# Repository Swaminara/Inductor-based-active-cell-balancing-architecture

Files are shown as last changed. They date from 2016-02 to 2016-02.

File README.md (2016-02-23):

# Inductor-based-active-cell-balancing-architecture
This repository contains the hardware design files of a modular inductor-based active cell balancing architecture proposed in CODES+ISSS '14 under the title "Verification of Balancing Architectures for Modular Batteries".

If you want to use the hardware files in this repository in your scientific publications, please reference it by the following bibtex citation

@inproceedings{lsn:2014,
  url = {  https://lukasiewycz.github.io/pdf/2014-CODES%2BISSS-Verification%20of%20Balancing%20Architectures%20for%20Modular%20Batteries.pdf  },
  doi = { 10.1145/2656075.2656104 },
  pages = { 30:1--30:10 },
  month = { 10 },
  year = { 2014 },
  location = { India },
  booktitle = { Proceedings of the 12th International Conference on Hardware/Software Codesign and System Synthesis (CODES+ISSS 2014) },
  author = { Martin Lukasiewycz and Sebastian Steinhorst and Swaminathan Narayanaswamy },
  title = { Verification of Balancing Architectures for Modular Batteries },
}

This repository is protected under the MIT license as attached.

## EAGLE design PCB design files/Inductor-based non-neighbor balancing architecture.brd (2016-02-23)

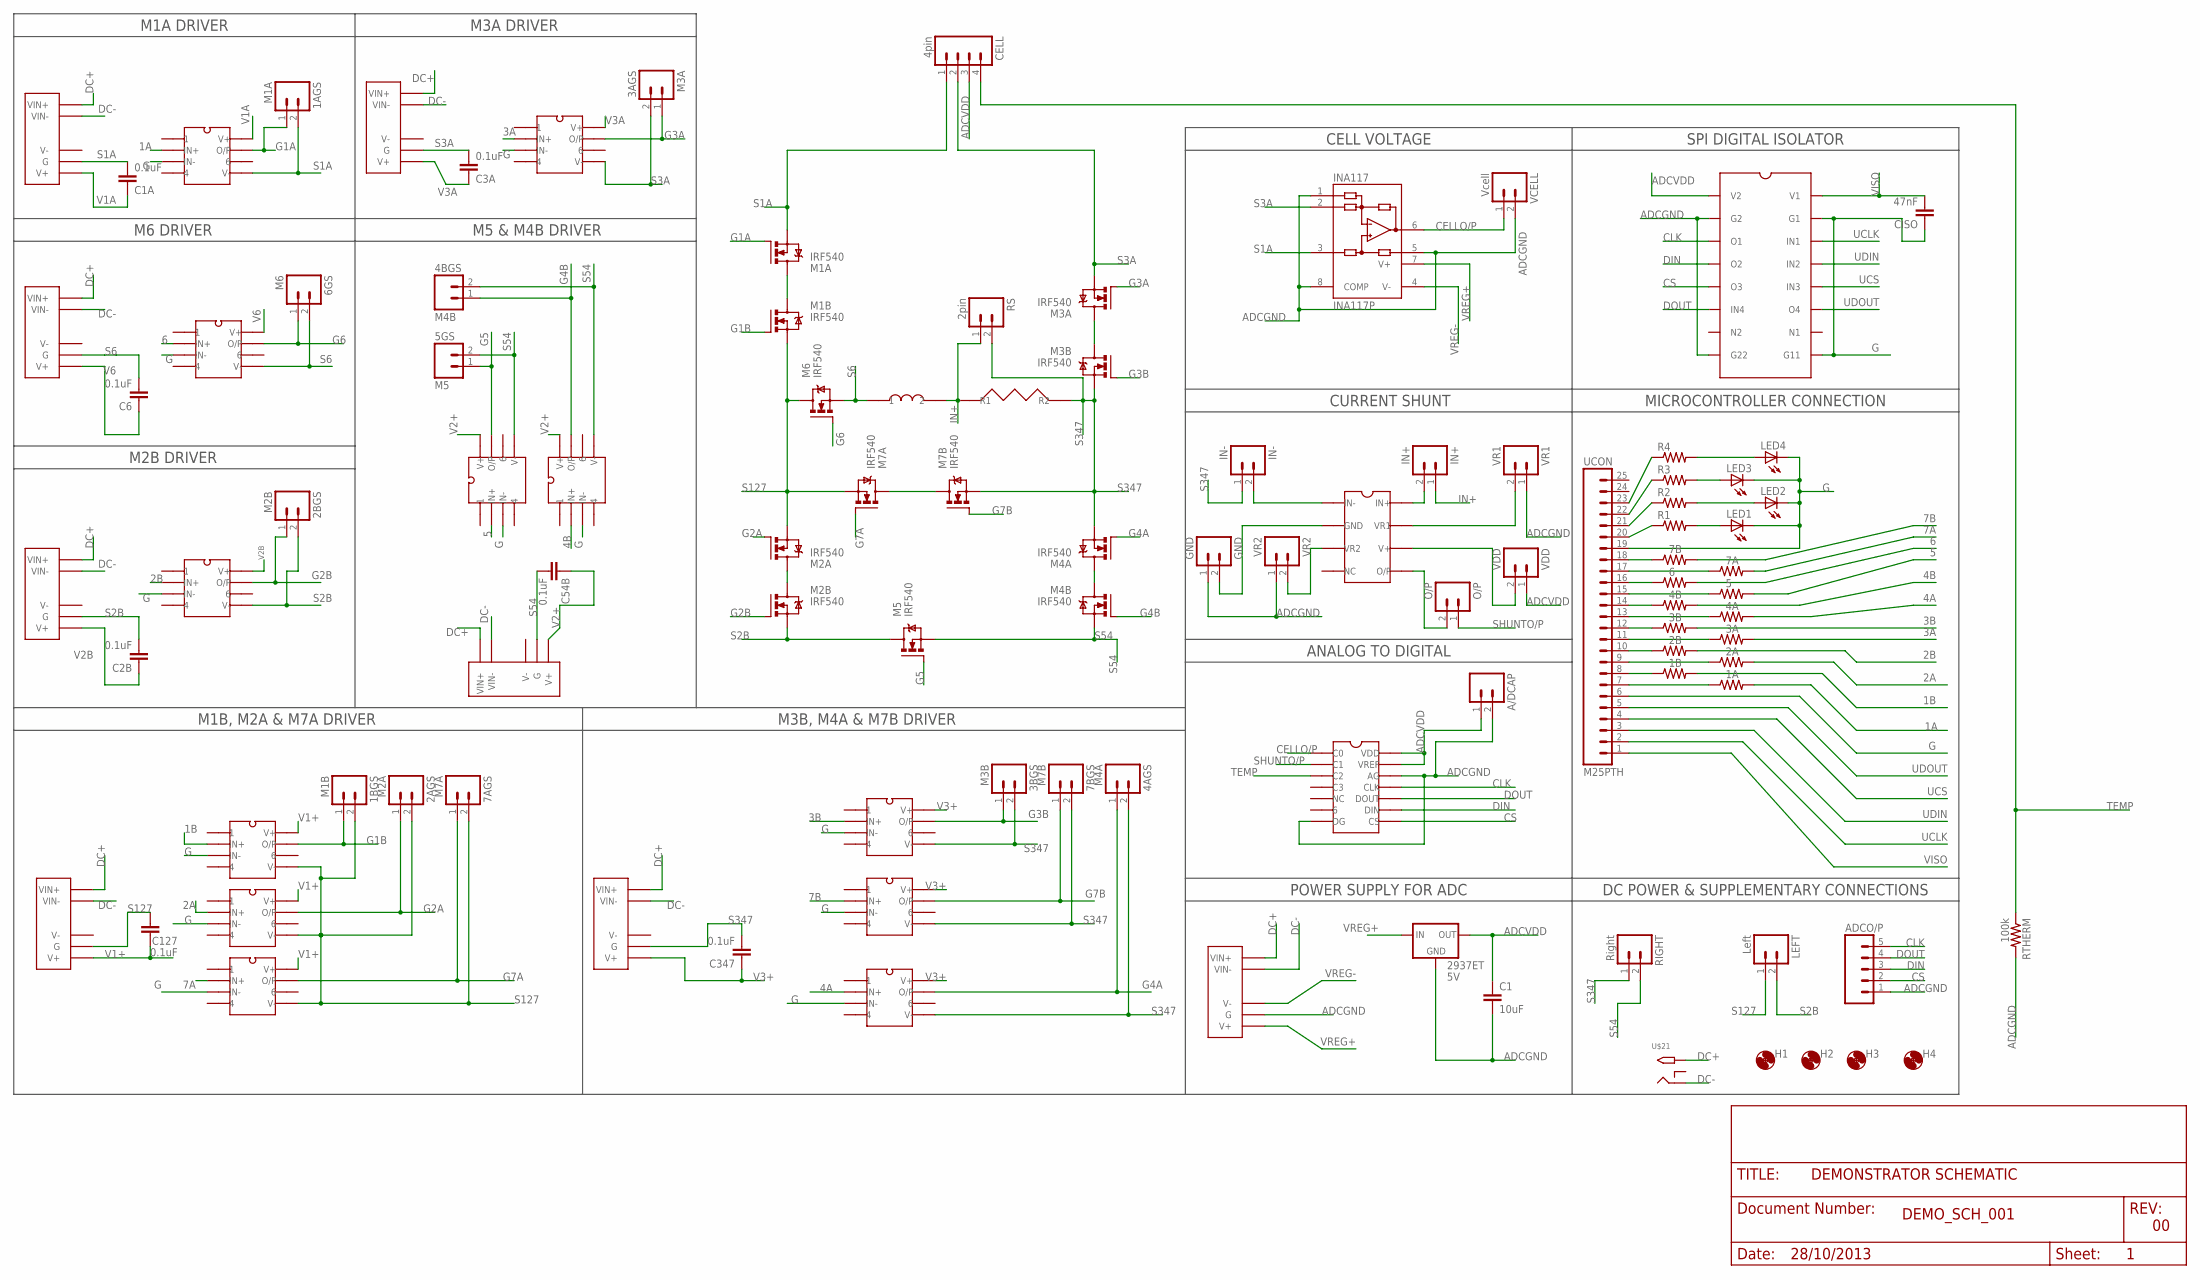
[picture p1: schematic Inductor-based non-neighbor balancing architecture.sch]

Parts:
1A, 1B, 2A, 2B, 3A, 3B, 4A, 4B, 5, 6, 7A, 7B: 220; AXIAL-0.5
1AGS: M1A; 1X02
1BGS: M1B; 1X02
2AGS: M2A; 1X02
2BGS: M2B; 1X02
3AGS: M3A; 1X02
3BGS: M3B; 1X02
4AGS: M4A; 1X02
4BGS: M4B; 1X02
5GS: M5; 1X02
6GS: M6; 1X02
7AGS: M7A; 1X02
7BGS: M7B; 1X02
2937ET: 5V; 78XXS
A/DCAP: M02PTH; 1X02
AD8210: CSM
ADC: ADC; DIL14
ADCO/P: M05PTH; 1X05
C1: 10uF; CAP-PTH-5MM
C1A, C2B, C3A, C6, C54B, C127, C347: 0.1uF; CAP-PTH-5MM
CELL: 4pin; 1X04
CISO: 47nF; CAP-PTH-5MM
DC/DC1A: 1A; DC-DC
DC/DC2B: 2B; DC-DC
DC/DC3A: 3A; DC-DC
DC/DC6: 6; DC-DC
DC/DC45: 4B5; DC-DC
DC/DC127: 1B2A7A; DC-DC
DC/DC347: 3B4A7B; DC-DC
DC/DC-ADC: ADC; DC-DC
GND: GND; 1X02
H1, H2, H3, H4: MOUNT-HOLE3.0; 3,0
HCPL902J: HCPL902
IN+: IN+; 1X02
IN-: IN-; 1X02
INA117: INA117P; DIL08
LED1, LED2, LED3, LED4: LEDCHIPLED_0805; CHIPLED_0805
LEFT: Left; 1X02
M1A, M1B, M2A, M2B, M3A, M3B, M4A, M4B, M5, M6, M7A, M7B: IRF540; TO220BV
M1AD: M1A; OPTO3180
M1BD: M1B; OPTO3180
M2AD: M2A; OPTO3180
M2BD: M2B; OPTO3180
M3AD: M3A; OPTO3180
M3BD: M3B; OPTO3180
M4AD: M4A; OPTO3180
M4BD: M4B; OPTO3180
M5D: M5; OPTO3180
M6D: M6; OPTO3180
M7AD: M7A; OPTO3180
M7BD: M7B; OPTO3180
O/P: O/P; 1X02
R1, R2, R3, R4: R-US_R0805; R0805
RIGHT: Right; 1X02
RS: 2pin; 1X02
RTHERM: 100k; AXIAL-0.5
U$1: INDFINAL; IND1MHFINAL
U$3: RSHUNT
U$21: 2.1MMJACKTHM; PJ-102A
UCON: M25PTH; 1X25
VCELL: Vcell; 1X02
VDD: VDD; 1X02
VR1: VR1; 1X02
VR2: VR2; 1X02

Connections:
1A: 1A.P$2 (2), M1AD.IN+
1B: 1B.P$2 (2), M1BD.IN+
2A: 2A.P$2 (2), M2AD.IN+
2B: 2B.P$2 (2), M2BD.IN+
3A: 3A.P$2 (2), M3AD.IN+
3B: 3B.P$2 (2), M3BD.IN+
4A: 4A.P$2 (2), M4AD.IN+
4B: 4B.P$2 (2), M4BD.IN+
5: 5.P$2 (2), M5D.IN+
6: 6.P$2 (2), M6D.IN+
7A: 7A.P$2 (2), M7AD.IN+
7B: 7B.P$2 (2), M7BD.IN+
ADCGND: 2937ET.GND, A/DCAP.2, ADC.AGND (AG), ADC.DGND (DG), ADCO/P.1, C1.2, DC/DC-ADC.G, GND.1, HCPL902J.G2, HCPL902J.G22, INA117.1 (REFB), INA117.5 (REFA), INA117.8 (COMP), RTHERM.P$2 (2), VCELL.2, VR1.1, VR2.1
ADCVDD: 2937ET.OUT, A/DCAP.1, ADC.VDD, ADC.VREF, C1.1, CELL.3, HCPL902J.V2, VDD.1
CELLO/P: ADC.CH0 (C0), INA117.6 (OUT), VCELL.1
CLK: ADC.CLK, ADCO/P.5, HCPL902J.OUT1 (O1)
CS: ADC.CS, ADCO/P.2, HCPL902J.OUT3 (O3)
DC+: DC/DC1A.VIN+, DC/DC2B.VIN+, DC/DC3A.VIN+, DC/DC6.VIN+, DC/DC45.VIN+, DC/DC127.VIN+, DC/DC347.VIN+, DC/DC-ADC.VIN+, U$21.TIP
DC-: DC/DC1A.VIN-, DC/DC2B.VIN-, DC/DC3A.VIN-, DC/DC6.VIN-, DC/DC45.VIN-, DC/DC127.VIN-, DC/DC347.VIN-, DC/DC-ADC.VIN-, U$21.RING
DIN: ADC.DIN, ADCO/P.3, HCPL902J.OUT2 (O2)
DOUT: ADC.DOUT, ADCO/P.4, HCPL902J.IN4
G: CISO.1, HCPL902J.G1, HCPL902J.G11, LED1.C, LED2.C, LED3.C, LED4.C, M1AD.IN-, M1BD.IN-, M2AD.IN-, M2BD.IN-, M3AD.IN-, M3BD.IN-, M4AD.IN-, M4BD.IN-, M5D.IN-, M6D.IN-, M7AD.IN-, M7BD.IN-, UCON.6, UCON.19
G1A: 1AGS.1, M1A.G, M1AD.O/P
G1B: 1BGS.1, M1B.G, M1BD.O/P
G2A: 2AGS.1, M2A.G, M2AD.O/P
G2B: 2BGS.1, M2B.G, M2BD.O/P
G3A: 3AGS.1, M3A.G, M3AD.O/P
G3B: 3BGS.1, M3B.G, M3BD.O/P
G4A: 4AGS.1, M4A.G, M4AD.O/P
G4B: 4BGS.1, M4B.G, M4BD.O/P
G5: 5GS.1, M5.G, M5D.O/P
G6: 6GS.1, M6.G, M6D.O/P
G7A: 7AGS.1, M7A.G, M7AD.O/P
G7B: 7BGS.1, M7B.G, M7BD.O/P
IN+: IN+.1, RS.1, U$1.2, U$3.R1
unnamed: M1A.D, M1B.D
unnamed: M4A.D, M4B.D
unnamed: AD8210.VR2, VR2.2
unnamed: M7A.D, M7B.D
unnamed: M2A.D, M2B.D
unnamed: AD8210.IN-, IN-.2
unnamed: AD8210.GND, GND.2
unnamed: AD8210.V+, VDD.2
unnamed: M3A.D, M3B.D
unnamed: AD8210.O/P, O/P.2
unnamed: AD8210.VR1, VR1.2
unnamed: AD8210.IN+, IN+.2
unnamed: 1A.P$1 (1), UCON.7
unnamed: 1B.P$1 (1), UCON.8
unnamed: 2A.P$1 (1), UCON.9
unnamed: 2B.P$1 (1), UCON.10
unnamed: 3A.P$1 (1), UCON.11
unnamed: 3B.P$1 (1), UCON.12
unnamed: 4A.P$1 (1), UCON.13
unnamed: 4B.P$1 (1), UCON.14
unnamed: 5.P$1 (1), UCON.15
unnamed: 6.P$1 (1), UCON.16
unnamed: 7A.P$1 (1), UCON.17
unnamed: 7B.P$1 (1), UCON.18
unnamed: LED2.A, R2.2
unnamed: LED1.A, R1.2
unnamed: LED4.A, R4.2
unnamed: R2.1, UCON.21
unnamed: R3.1, UCON.22
unnamed: LED3.A, R3.2
unnamed: R4.1, UCON.23
R4: R1.1, UCON.20
S1A: 1AGS.2, C1A.2, CELL.1, DC/DC1A.G, INA117.3 (+IN), M1A.S, M1AD.V-
S2B: 2BGS.2, C2B.2, DC/DC2B.G, LEFT.2, M2B.S, M2BD.V-, M5.D
S3A: 3AGS.2, C3A.2, CELL.2, DC/DC3A.G, INA117.2 (-IN), M3A.S, M3AD.V-
S6: 6GS.2, C6.2, DC/DC6.G, M6.S, M6D.V-, U$1.1
S54: 4BGS.2, 5GS.2, C54B.2, DC/DC45.G, M4B.S, M4BD.V-, M5.S, M5D.V-, RIGHT.2
S127: 1BGS.2, 2AGS.2, 7AGS.2, C127.2, DC/DC127.G, LEFT.1, M1B.S, M1BD.V-, M2A.S, M2AD.V-, M6.D, M7A.S, M7AD.V-
S347: 3BGS.2, 4AGS.2, 7BGS.2, C347.2, DC/DC347.G, IN-.1, M3B.S, M3BD.V-, M4A.S, M4AD.V-, M7B.S, M7BD.V-, RIGHT.1, RS.2, U$3.R2
SHUNTO/P: ADC.CH1 (C1), O/P.1
TEMP: ADC.CH2 (C2), CELL.4, RTHERM.P$1 (1)
UCLK: HCPL902J.IN1, UCON.2
UCS: HCPL902J.IN3, UCON.4
UDIN: HCPL902J.IN2, UCON.3
UDOUT: HCPL902J.OUT4 (O4), UCON.5
V1+: C127.1, DC/DC127.V+, M1BD.V+, M2AD.V+, M7AD.V+
V1A: C1A.1, DC/DC1A.V+, M1AD.V+
V2+: C54B.1, DC/DC45.V+, M4BD.V+, M5D.V+
V2B: C2B.1, DC/DC2B.V+, M2BD.V+
V3+: C347.1, DC/DC347.V+, M3BD.V+, M4AD.V+, M7BD.V+
V3A: C3A.1, DC/DC3A.V+, M3AD.V+
V6: C6.1, DC/DC6.V+, M6D.V+
VISO: CISO.2, HCPL902J.V1, UCON.1
VREG+: 2937ET.IN, DC/DC-ADC.V+, INA117.7 (V+)
VREG-: DC/DC-ADC.V-, INA117.4 (V-)

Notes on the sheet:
M1A DRIVER
M3A DRIVER
M6 DRIVER
M5 & M4B DRIVER
M2B DRIVER
M1B, M2A & M7A DRIVER
M3B, M4A & M7B DRIVER
CELL VOLTAGE
CURRENT SHUNT
ANALOG TO DIGITAL
SPI DIGITAL ISOLATOR
MICROCONTROLLER CONNECTION
POWER SUPPLY FOR ADC
DC POWER & SUPPLEMENTARY CONNECTIONS

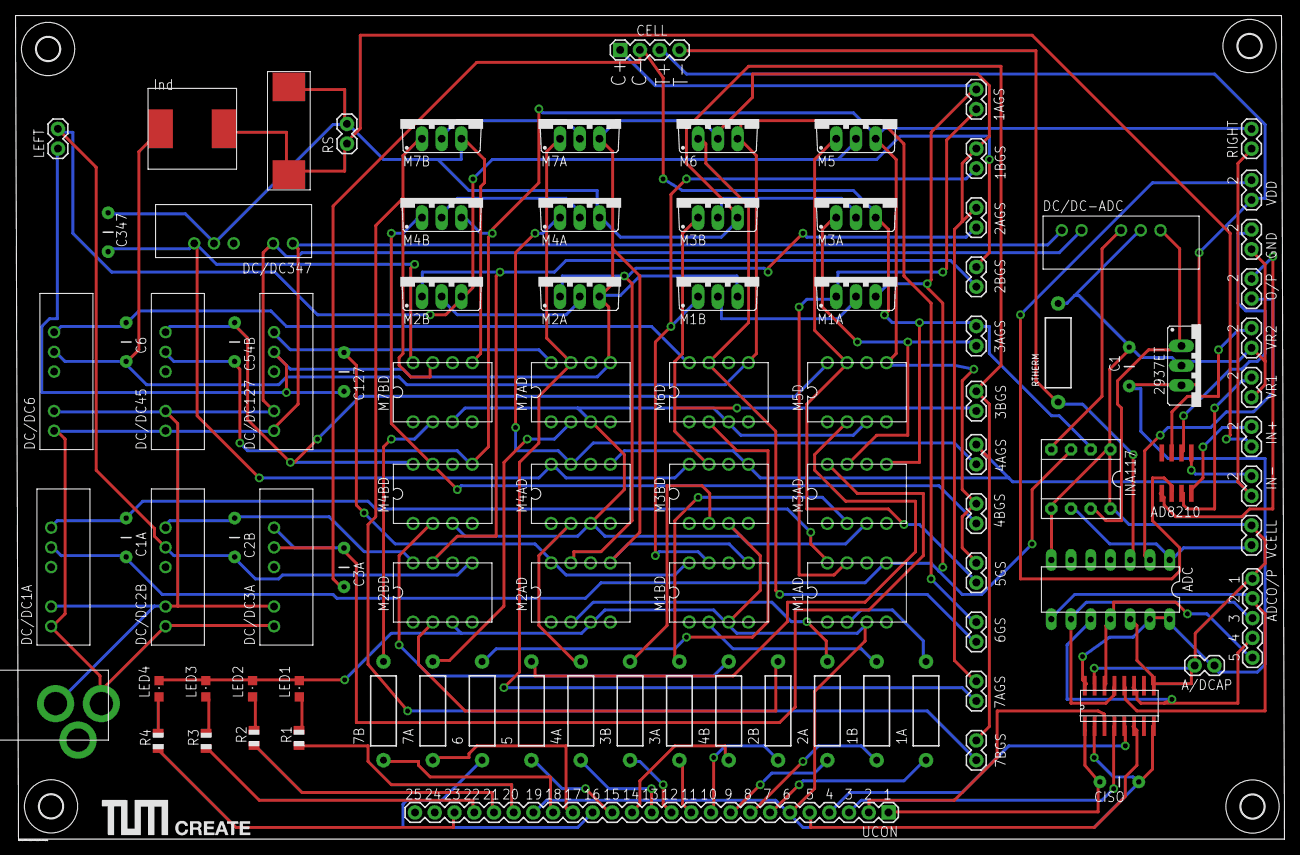
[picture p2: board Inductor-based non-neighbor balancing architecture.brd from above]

Board: 2 copper layers, 163.4 x 106.0 mm, 101 parts (0 on the bottom side), 90 nets.

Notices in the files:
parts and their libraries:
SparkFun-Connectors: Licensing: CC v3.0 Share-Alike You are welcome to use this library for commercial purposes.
